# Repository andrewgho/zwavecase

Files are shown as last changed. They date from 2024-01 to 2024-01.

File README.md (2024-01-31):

zwavecase - minimal case for Raspberry Pi 4 B+ with RaZberry 7 Pro
==================================================================

This is a minimalist base plate style case that fits a Raspberry Pi 4 B+ with
the [RaZberry 7 Pro](https://z-wave.me/products/razberry/) Z-wave shield which
comes with an integrated antenna. The case holds the antenna out from the body
and keeps the Raspberry Pi stable on a flat surface.

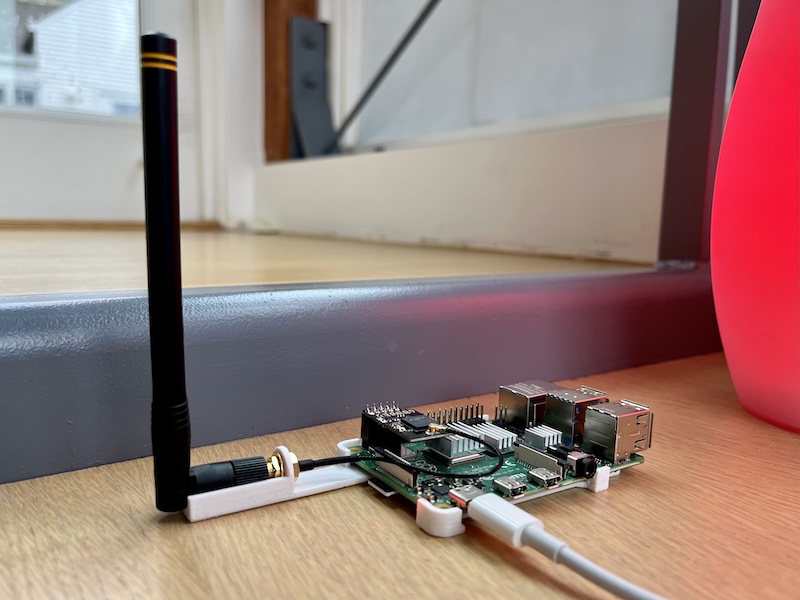
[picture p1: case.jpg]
Image of Raspberry Pi 4 B+ with Razpberry 7 Pro mounted


The case should be snap-fit, but you can also use (short) M2.5 screws if you
want a more permanent attachment.

The repository includes OpenSCAD source (warning: pretty messy) and a printable
STL. It also includes a PrusaSlicer G-code for PETG for the Prusa Mini, which
happens to be the printer I own.

License
-------

This design is licensed by
[Andrew Ho](https://zeuscat.com/andrew/) under the
[Creative Commons - Attribution license](https://creativecommons.org/licenses/by/4.0/).

The RaZberry Pro is sold by
[Smart Systems Distribution Sàrl](https://smartsd.ch/). This repository is not
related to endorsed by the latter.

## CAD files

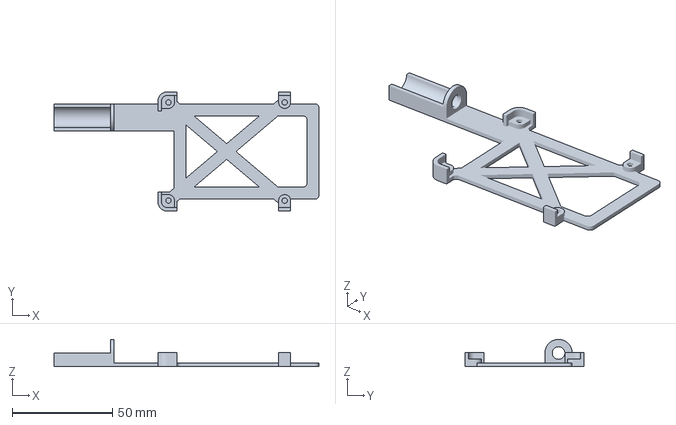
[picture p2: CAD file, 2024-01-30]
case.3mf
132.2 x 59.6 x 13.6 mm

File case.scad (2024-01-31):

// case.scad - Raspberry Pi 4 B+ case with antenna mount for RaZberry Pro 7
// Andrew Ho <andrew@zeuscat.com>
//
// https://z-wave.me/products/razberry/

// Overall Raspberry Pi 4 B+ dimensions from:
// https://datasheets.raspberrypi.com/rpi4/raspberry-pi-4-mechanical-drawing.pdf
length = 85;                            // Overall PCB length (longest dimension)
width = 56;                             // Overall PCB width
corner_radius = 3;                      // PCB corner radius
hole_offset = 3.5;                      // Distance between PCB edge and screw hole
hole_id = 2.7;                          // Inner screw hole diameter
hole_od = 6;                            // Diameter of screw hole free area
hole_length_center_offset = 58;         // Distance between screw hole centers, along length
hole_width_center_offset = 49;          // Distance between screw hole centers, along width

// Measured dimensions of RaZberry Pro 7 Linx antenna
antenna_screw_od = 6.25;                // Outer diameter of bolt mount
antenna_bottom_shaft_od = 10;           // Outer diameter of external antenna shaft

// Our design parameters
thickness = 1.8;                        // Overall shell thickness
mount_post_height = thickness + 2;      // How high the mount posts rise from ground z = 0
lip_height = mount_post_height + 1.5;   // How high the walls surrounding the PCB from PCB z = 0
thickness2 = thickness * 2;

antenna_boom_length = 60;               // Length of extension from attachment to base plate
antenna_support_length = 30;            // How much of that boom length is supporting antenna shaft
antenna_boom_width =
  antenna_bottom_shaft_od + thickness2;

// Rendering parameters
e = 0.1;
e2 = e * 2;
$fn = 60;

// Create a rounded rectangular solid with a given corner radius
module rounded_cube(length, width, height, radius) {
  module corner() {
    cylinder(r = radius, h = height);
  }
  hull() {
    translate([radius, radius]) corner();
    translate([radius, width - radius]) corner();
    translate([length - radius, width - radius]) corner();
    translate([length - radius, radius]) corner();
  }
}

// Corner mount post, without lip, designed to be at (0, 0); will be reflected for other corner
module mount_post_origin() {
  difference() {
    hull() {
      cube([hole_offset + (hole_od / 2), hole_offset, mount_post_height]);
      cube([hole_offset, hole_offset + (hole_od / 2), mount_post_height]);
      translate([corner_radius, corner_radius]) {
        cylinder(r = corner_radius, h = mount_post_height);
      }
      translate([hole_offset, hole_offset]) {
        cylinder(d = hole_od, h = mount_post_height);
      }
    }
    translate([hole_offset, hole_offset, -e]) {
      cylinder(d = hole_id, h = mount_post_height + e2);
    }
  }
}

// Edge mount post, without lip; will be reflected for other edge
module mount_post_edge() {
  difference() {
    hull() {
      translate([hole_offset + hole_length_center_offset, hole_offset]) {
        cylinder(d = hole_od, h = mount_post_height);
      }
      translate([(hole_offset + hole_length_center_offset) - corner_radius, 0]) {
        cube([corner_radius * 2, e, mount_post_height]);
      }
    }
    translate([hole_offset + hole_length_center_offset, hole_offset, -e]) {
      cylinder(d = hole_id, h = mount_post_height + e2);
    }
  }
}

// Corner lip which nestles around PCB corner, at (0, 0) and to be reflected for other corner
// TODO: interferes slightly with USB-C power port; pare back length to fit
module lip_origin() {
  difference() {
    hull() {
      translate([corner_radius, -thickness, 0]) {
        cube([corner_radius + thickness, thickness, thickness + lip_height]);
      }
      translate([corner_radius, corner_radius, 0]) {
        cylinder(r = corner_radius + thickness, h = thickness + lip_height);
      }
      translate([-thickness, corner_radius, 0]) {
        cube([thickness, corner_radius + thickness, thickness + lip_height]);
      }
    }
    translate([0, 0, thickness]) {
      hull() {
        translate([corner_radius, 0]) {
          cube([corner_radius + thickness + e, (corner_radius * 2) + e, lip_height + e]);
        }
        translate([corner_radius, corner_radius]) {
          cylinder(r = corner_radius, h = lip_height + e);
        }
        translate([0, corner_radius]) {
          cube([(corner_radius * 2) + e, corner_radius + thickness + e,
                lip_height + e]);
        }
      }
    }
  }
}

// Lip that goes with edge mount post
module lip_edge() {
  translate([(hole_offset + hole_length_center_offset) - corner_radius, -thickness]) {
    cube([corner_radius * 2, thickness, thickness + lip_height]);
  }
}

// Base plate, designed to be invisible underneath the Raspberry Pi PCB
module base_plate() {
  inner_length = 0.85 * length;
  inner_width = 0.85 * width;
  inner_roadwidth = hole_od;
  inner_corner_radius = 2;
  module corner() {
    cylinder(r = corner_radius, h = thickness);
  }
  module strut() {
    hull() {
      translate([corner_radius, corner_radius]) corner();
      translate([hole_offset + hole_length_center_offset, width - hole_offset]) corner();
    }
  }
  translate([(length - inner_length) / 2, (width - inner_width) / 2]) {
    difference() {
      rounded_cube(inner_length, inner_width, thickness, inner_corner_radius);
      translate([inner_roadwidth, inner_roadwidth, -e]) {
        rounded_cube(inner_length - (2 * inner_roadwidth),
                     inner_width - (2 * inner_roadwidth),
                     thickness + e2, inner_corner_radius);
      }
    }
  }
  translate([(length - inner_length) / 2, (width - ((0.15 / 2) * width)) - antenna_boom_width]) {
    mirror([1, 0, 0]) antenna_base();
  }
  strut();
  translate([0, width, 0]) mirror([0, 1, 0]) strut();
}

// The boom that comes out and includes antenna mount and support
module antenna_base() {
  // Base of the boom
  cube([antenna_boom_length, antenna_boom_width, thickness]);
  translate([antenna_boom_length - antenna_support_length, 0, thickness]) {
    // Hoop-shaped antenna screw mount
    difference() {
      hull() {
        cube([thickness, antenna_boom_width, e]);
        translate([0, thickness + (antenna_bottom_shaft_od / 2), antenna_bottom_shaft_od / 2]) {
          rotate(90, [0, 1, 0]) {
            cylinder(d = thickness2 + antenna_bottom_shaft_od, h = thickness);
          }
        }
      }
      translate([-e, thickness + (antenna_bottom_shaft_od / 2), antenna_bottom_shaft_od / 2]) {
        rotate(90, [0, 1, 0]) {
          cylinder(d = antenna_screw_od, h = thickness + e2);
        }
      }
    }
    // Extended support that cradles the antenna shaft
    difference() {
      cube([antenna_support_length, antenna_boom_width, antenna_bottom_shaft_od / 2]);
      translate([-e, thickness + (antenna_bottom_shaft_od / 2), antenna_bottom_shaft_od / 2]) {
        rotate(90, [0, 1, 0]) {
          cylinder(d = antenna_bottom_shaft_od, h = antenna_support_length + e2);
        }
      }
    }
  }
}

base_plate();
mount_post_origin();
mount_post_edge();
lip_origin();
lip_edge();
translate([0, (hole_offset * 2) + hole_width_center_offset]) mirror([0, 1, 0]) {
  mount_post_origin();
  mount_post_edge();
  lip_origin();
  lip_edge();
}

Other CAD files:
case.stl

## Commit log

2024-01-23 Initial repository creation
    [case.scad, rpi4.scad]
2024-01-29 Starting over from scratch
    [case.scad, case_complex.scad]
2024-01-29 More progress
    [case.scad]
2024-01-29 Remove earlier model
    [case_complex.scad]
2024-01-29 Add Makefile and STL
    [case.stl]
2024-01-29 Add PrusaSlicer artifacts
    [case.3mf]
2024-01-29 Save settings
    [case.3mf]
2024-01-30 Increase size for strength
    Increase overall shell thickness, move lip up slightly, and extend the amount
    of antenna that is supported. Remove the gutter between the corner screw mount
    holes and the outer lip.
    [case.3mf, case.scad, case.stl]
2024-01-31 Remove unused Raspberry Pi 4 reference model
    [rpi4.scad]
2024-01-31 Clean up source order
    [case.scad, case.stl]
